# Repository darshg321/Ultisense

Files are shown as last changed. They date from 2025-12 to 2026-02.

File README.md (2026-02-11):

# Ultisense

an esp32-s3 devboard made to sense as many things as possible

has:
- an NFC antenna
- 6DOF IMU
- VOC air sensor
- humidity & temperature sensor
- color & ambient light sensor
- magnetometer

it additionally has:
- microphone
- two speakers
- microSD card


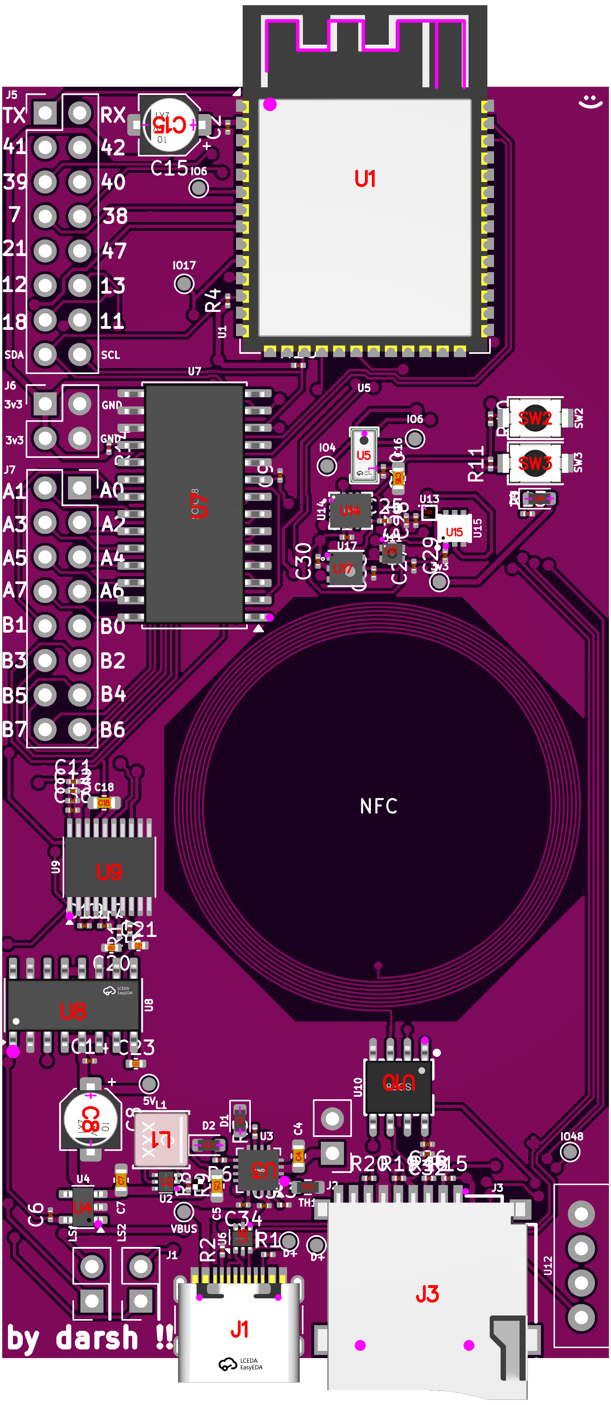
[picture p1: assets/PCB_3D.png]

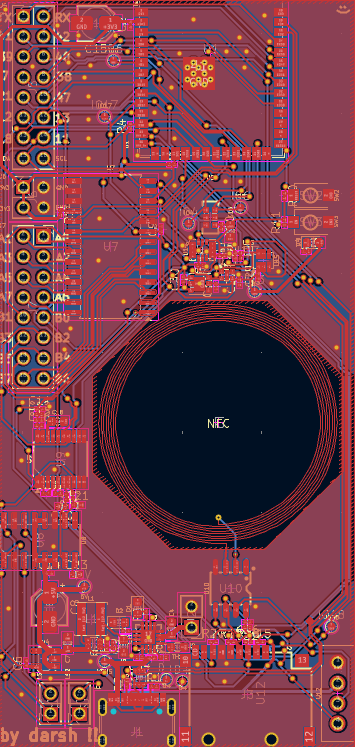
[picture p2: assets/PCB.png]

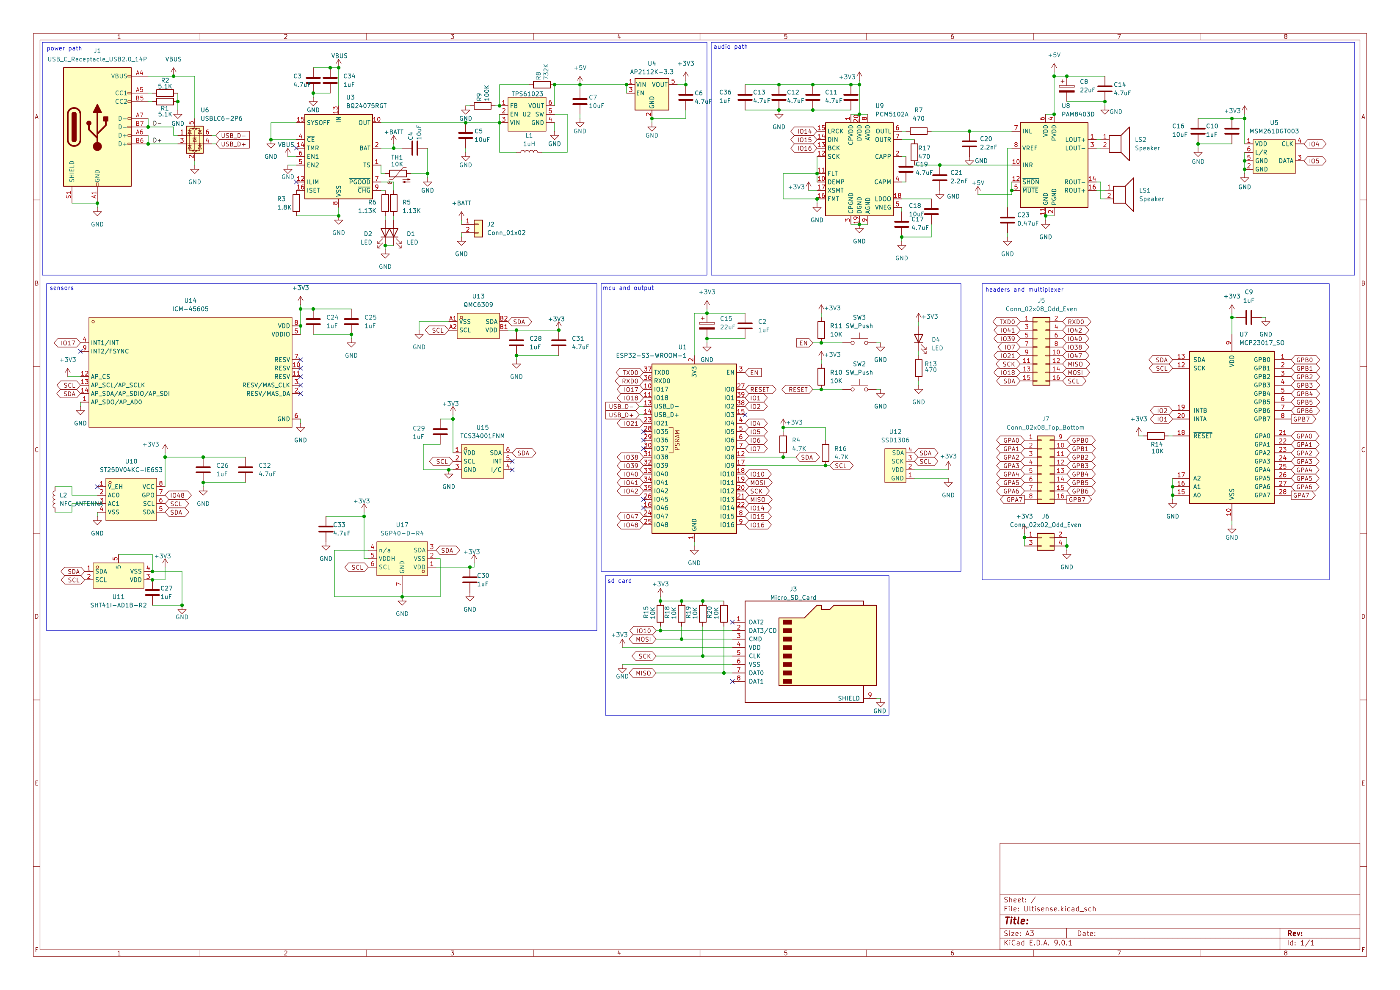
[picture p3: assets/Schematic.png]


## BOM

|Item|Qty |Price (USD) |
|----|---|---|
|PCB |5 |4 |
|PCBA|2 |161.91 |
|Shipping (GSDL)| |12.36 |

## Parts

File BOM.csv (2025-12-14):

Item | Qty | Price (USD)
PCB | 5 | 4
PCBA | 2 | 161.91
Shipping (GSDL) |  | 12.36

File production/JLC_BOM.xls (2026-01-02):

Comment | Designator | Footprint | JLCPCB Part #
SGP40-D-R4 | U17 | DFN-6-EP(2.4x2.4) | C2874215
BQ24075RGT | U3 | QFN-16-EP(3x3) | C15464
USB_C_Receptacle_USB2.0_14P | J1 | SMD | C165948
AP2112K-3.3 | U4 | SOT-23-5 | C23380830
SW_Push | SW2,SW3 | SMD,4x3mm | C720477
TCS34001FNM | U15 | DFN-6(2x2.4) | C2153593
470 | R13,R17,R7 | 0201 | C473464
PCM5102A | U9 | TSSOP-20 | C107671
SHT41I-AD1B-R2 | U11 | DFN-4 | C3664410
4.7K | R16,R4 | 0201 | C138135
LED | D1,D2,D4 | 0603 | C2286
ICM-45605 | U14 | LGA-14 | C38673635
10uF | C16,C18,C4,C5,C7 | 0603 | C1691
2.2nF | C20,C21 | 0402 | C84703
732K | R8 | 0201 | C851791
QMC6309 | U13 | WLCSP-4(0.8x0.8) | C5439871
4.7uF | C11,C12,C13,C14,C17,C19,C3,C31,C32,C33,C6 | 0201 | C335103
1.13K | R5,R6 | 0201 | C166381
ESP32-S3-WROOM-1 | U1 | SMD,25.5x18mm | C2913202
1uH | L1 | SMD,4x4mm | C4555951
5.1K | R1,R2 | 0201 | C163490
USBLC6-2P6 | U6 | SOT-666-6 | C15999
100K | R9 | 0201 | C102685
22uF | C15,C8 | SMD,D4xL5.4mm | C72502
10K | TH1 | 0603 | C13564
Micro_SD_Card | J3 | SMD | C393941
1uF | C10,C2,C24,C25,C26,C27,C28,C29,C30,C34,C36,C9 | 0201 | C76929
MSM261DGT003 | U5 | LGA-6(2x4) | C48227730
TPS61023 | U2 | SOT-563 | C919459
0.47uF | C23 | 0402 | C47339
1.8K | R3 | 0201 | C158752
MCP23017_SO | U7 | SOIC-28-300mil | C629440
PAM8403D | U8 | SOIC-16 | C17337
ST25DV04KC-IE6S3 | U10 | SO-8 | C3304276
10K | R10,R11,R14,R15,R18,R19,R20 | 0201 | C106225

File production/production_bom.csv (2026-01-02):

Designator | Footprint | Quantity | Value | LCSC Part #
C10, C2, C24, C25, C26, C27, C28, C29, C30, C34, C36, C9 | 0201 | 12 | 1uF
C11, C12, C13, C14, C17, C19, C3, C31, C32, C33, C6 | 0201 | 11 | 4.7uF
C15, C8 | CP_Elec_4x5.4 | 2 | 22uF
C16, C18, C4, C5, C7 | 0603 | 5 | 10uF
C20, C21 | 0402 | 2 | 2.2nF
C23 | 0402 | 1 | 0.47uF
D1, D2, D4 | 0603 | 3 | LED
J1 | USB_C_Receptacle_HRO_TYPE-C-31-M-12 | 1 | USB_C_Receptacle_USB2.0_14P
J2 | PinHeader_1x02_P2.54mm_Vertical | 1 | Conn_01x02
J3 | TF-SMD_TF-PUSH | 1 | Micro_SD_Card
J5 | PinHeader_2x08_P2.54mm_Vertical | 1 | Conn_02x08_Odd_Even
J6 | PinHeader_2x02_P2.54mm_Vertical | 1 | Conn_02x02_Odd_Even
J7 | PinSocket_2x08_P2.54mm_Vertical | 1 | Conn_02x08_Top_Bottom
L1 | IND-SMD_L4.0-W4.0-A | 1 | 1uH
LS1, LS2 | PinHeader_2x01_P2.54mm_Vertical | 2 | Speaker
R1, R2 | 0201 | 2 | 5.1K
R10, R11, R14, R15, R18, R19, R20 | 0201 | 7 | 10K
R13, R17, R7 | 0201 | 3 | 470
R16, R4 | 0201 | 2 | 4.7K
R3 | 0201 | 1 | 1.8K
R5, R6 | 0201 | 2 | 1.13K
R8 | 0201 | 1 | 732K
R9 | 0201 | 1 | 100K
SW2, SW3 | SW-SMD_L3.9-W3.0-P4.45 | 2 | SW_Push
TH1 | 0603 | 1 | 10K
U1 | ESP32-S3-WROOM-1 | 1 | ESP32-S3-WROOM-1
U10 | SO-8_L4.9-W3.9-P1.27-LS5.9-BL | 1 | ST25DV04KC-IE6S3 | C3304276
U11 | SENSOR-SMD_4P-L1.5-W1.5-P1.00-TL | 1 | SHT41I-AD1B-R2 | C3664410
U12 | SSD1306 | 1 | SSD1306
U13 | X1-WLB0808-4_L0.8-W0.8-P0.40-TL | 1 | QMC6309 | C5439871
U14 | LGA-14_L3.0-W2.5-P0.50-TL | 1 | ICM-45605 | C38673635
U15 | DFN-6_L2.4-W2.0-P0.65-BL | 1 | TCS34001FNM | C2153593
U17 | DFN-6_L2.4-W2.4-P0.80-TL-EP | 1 | SGP40-D-R4 | C2874215
U2 | SOT-563_L1.6-W1.2-P0.50-LS1.6-BR | 1 | TPS61023
U3 | VQFN-16-1EP_3x3mm_P0.5mm_EP1.6x1.6mm | 1 | BQ24075RGT
U4 | SOT-23-5 | 1 | AP2112K-3.3
U5 | MIC-SMD_6P-L4.0-W2.0_LMD4020T261-OC3 | 1 | MSM261DGT003
U6 | SOT-666 | 1 | USBLC6-2P6
U7 | SOIC-28W_7.5x17.9mm_P1.27mm | 1 | MCP23017_SO
U8 | SOP-16_3.9x9.9mm_P1.27mm | 1 | PAM8403D
U9 | TSSOP-20_4.4x6.5mm_P0.65mm | 1 | PCM5102A

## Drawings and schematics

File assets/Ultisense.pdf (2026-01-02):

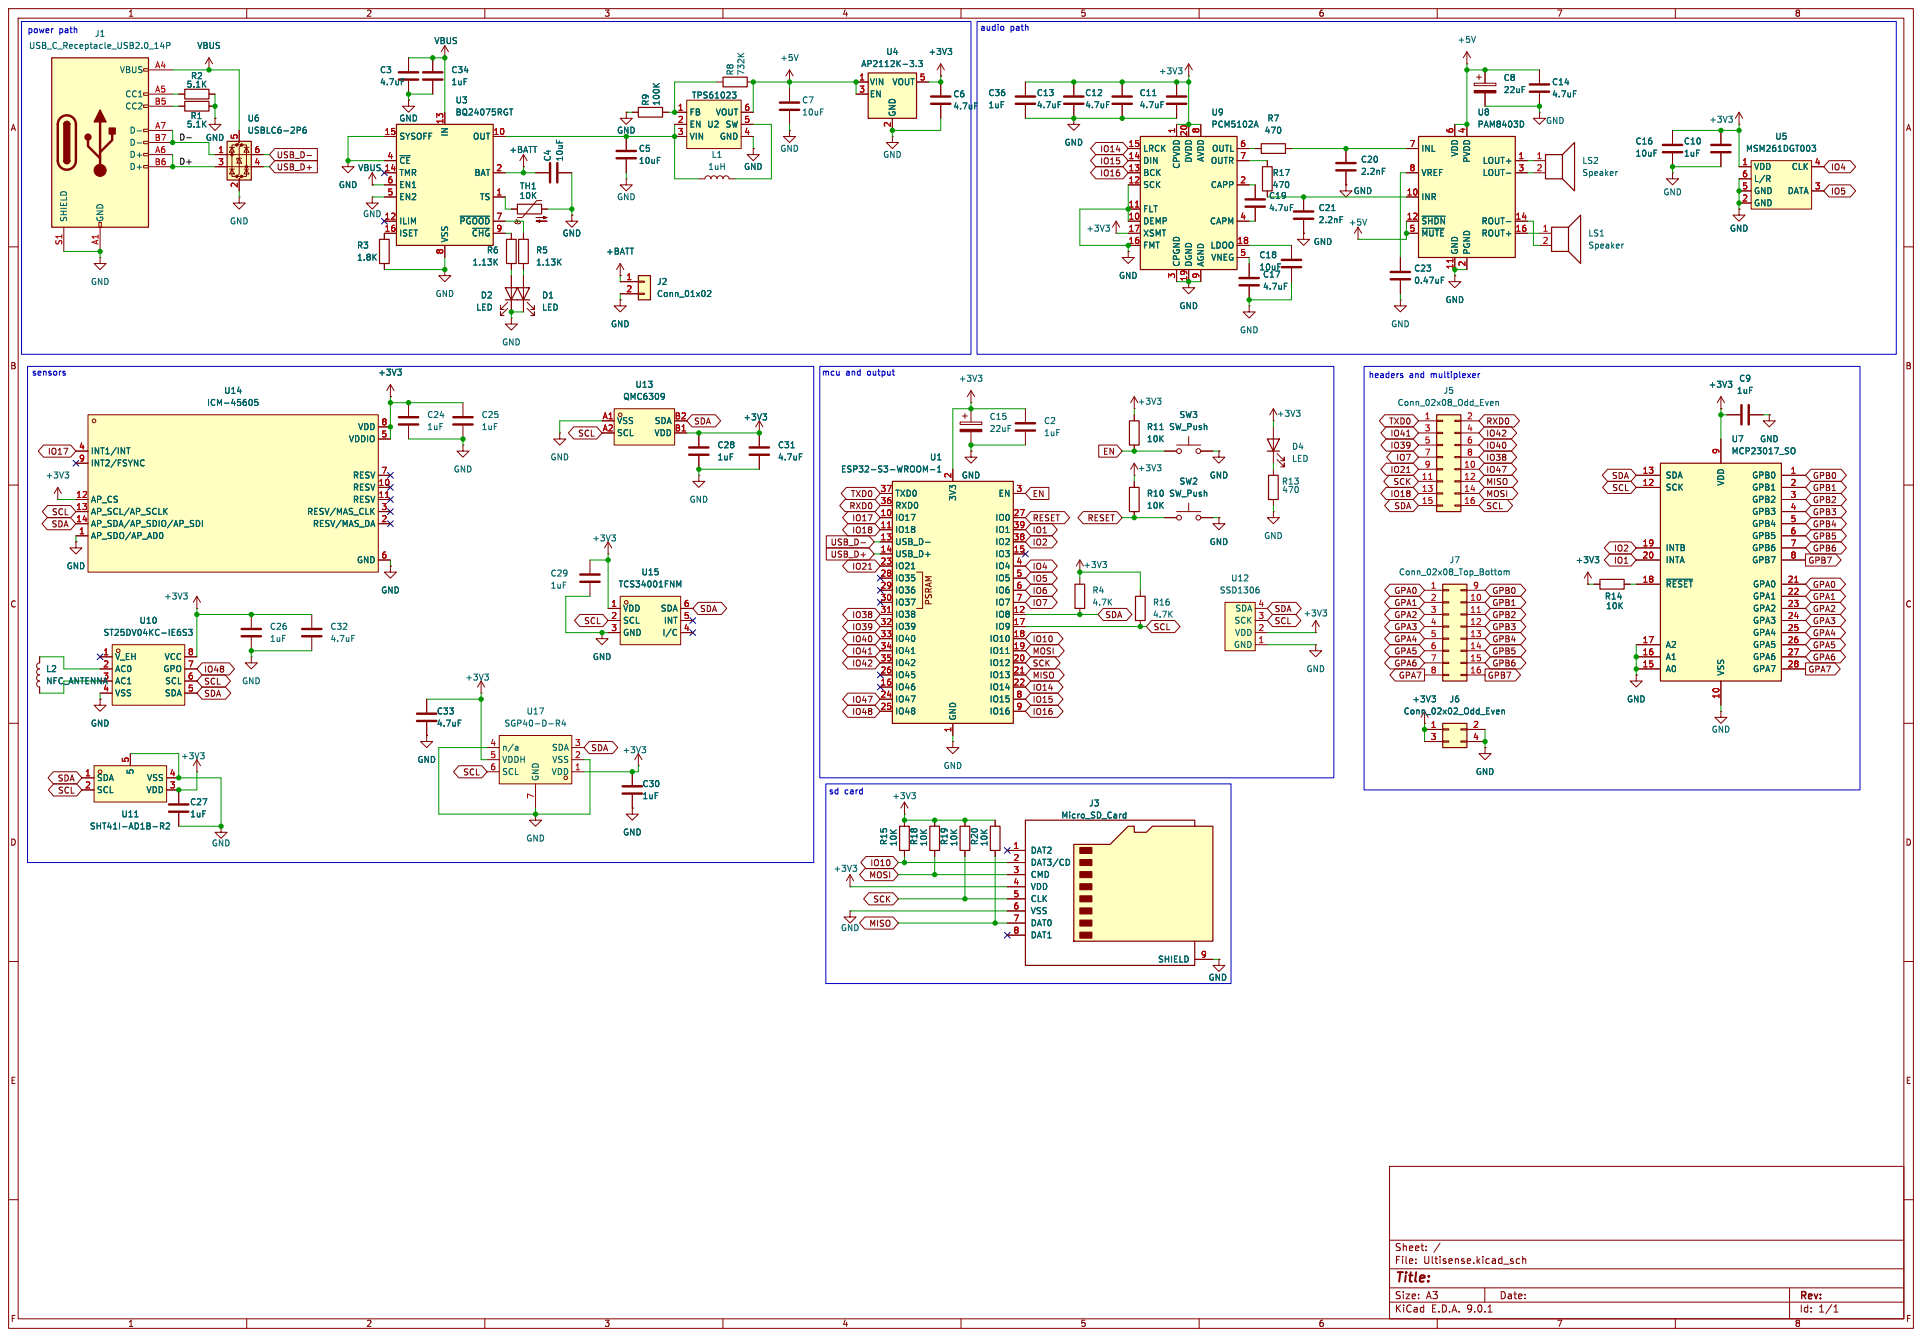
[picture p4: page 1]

8 OUT 10 BAT 2 TS 1 ~{PGOOD}7 ~{CHG}9 C34

8 OUT 10 BAT 2 TS 1 ~{PGOOD}7 ~{CHG}9 U3BQ24075RGT GND

9 OUTL 6 OUTR 7 CAPP 2 CAPM 4

+3V3 VDD 1 VSS 2 SDA 3 GND

EN MISO MOSI SCK

Id: 1/1 Title: File: Ultisense.kicad_sch Sheet: /

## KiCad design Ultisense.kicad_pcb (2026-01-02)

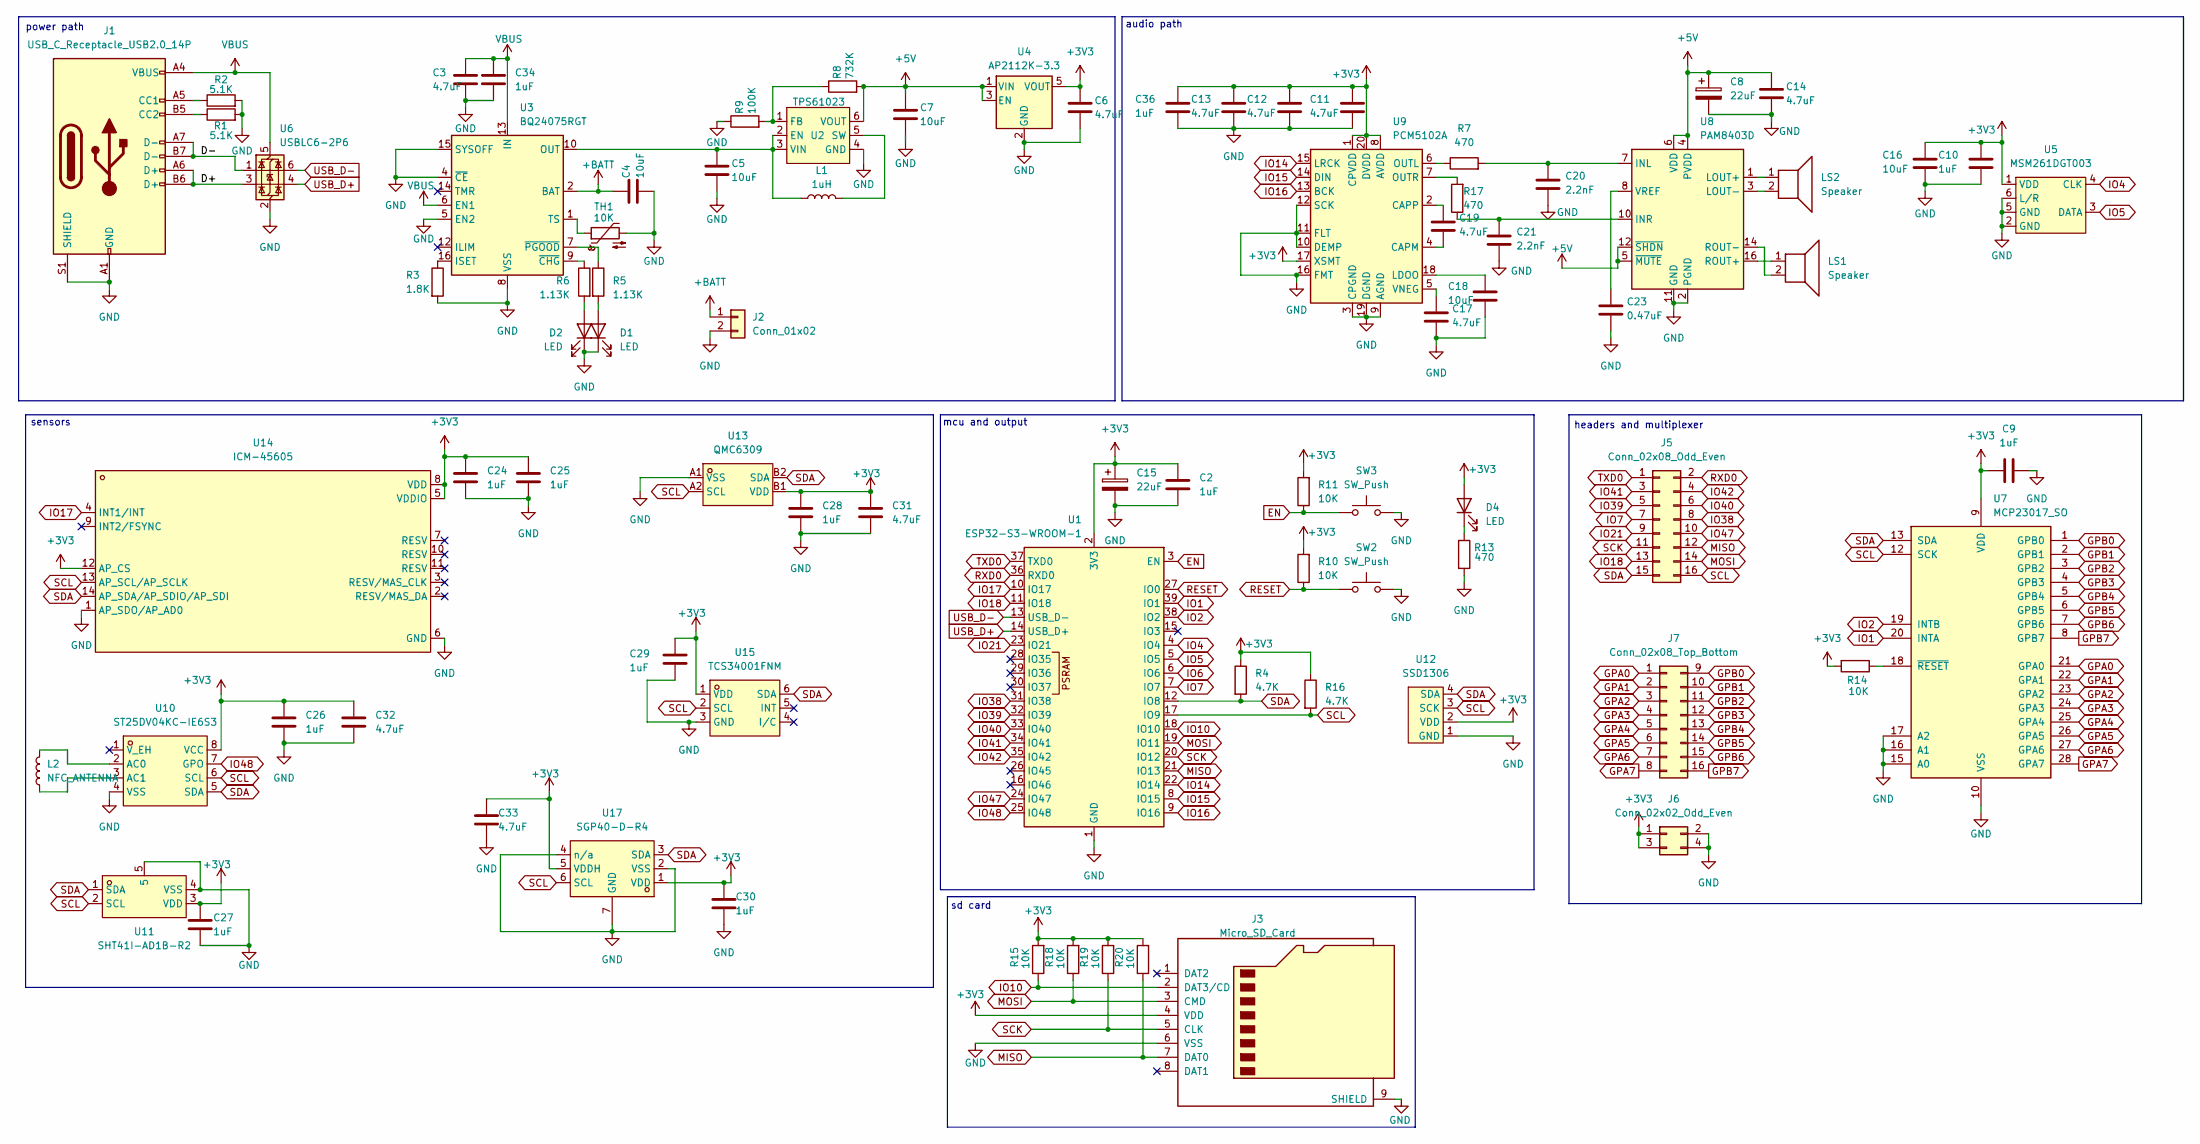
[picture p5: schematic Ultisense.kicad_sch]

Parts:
C2, C9, C10, C24, C25, C26, C27, C28, C29, C30, C34, C36: 1uF; C_0201_0603Metric
C3, C6, C11, C12, C13, C14, C17, C19, C31, C32, C33: 4.7uF; C_0201_0603Metric
C4, C5, C7, C16, C18: 10uF; C_0603_1608Metric
C8, C15: 22uF; CP_Elec_4x5.4
C20, C21: 2.2nF; C_0402_1005Metric
C23: 0.47uF; C_0402_1005Metric
D1, D2, D4: LED; LED_0603_1608Metric
J1: USB_C_Receptacle_USB2.0_14P; USB_C_Receptacle_HRO_TYPE-C-31-M-12
J2: Conn_01x02; PinHeader_1x02_P2.54mm_Vertical
J3: Micro_SD_Card; TF-SMD_TF-PUSH
J5: Conn_02x08_Odd_Even; PinHeader_2x08_P2.54mm_Vertical
J6: Conn_02x02_Odd_Even; PinHeader_2x02_P2.54mm_Vertical
J7: Conn_02x08_Top_Bottom; PinSocket_2x08_P2.54mm_Vertical
L1: 1uH; IND-SMD_L4.0-W4.0-A
L2: NFC_ANTENNA; NFC_Coil
LS1, LS2: Speaker; PinHeader_2x01_P2.54mm_Vertical
R1, R2: 5.1K; R_0201_0603Metric
R3: 1.8K; R_0201_0603Metric
R4, R16: 4.7K; R_0201_0603Metric
R5, R6: 1.13K; R_0201_0603Metric
R7, R13, R17: 470; R_0201_0603Metric
R8: 732K; R_0201_0603Metric
R9: 100K; R_0201_0603Metric
R10, R11, R14, R15, R18, R19, R20: 10K; R_0201_0603Metric
SW2, SW3: SW_Push; SW-SMD_L3.9-W3.0-P4.45
TH1: 10K; R_0603_1608Metric
U1: ESP32-S3-WROOM-1
U2: TPS61023; SOT-563_L1.6-W1.2-P0.50-LS1.6-BR
U3: BQ24075RGT; VQFN-16-1EP_3x3mm_P0.5mm_EP1.6x1.6mm
U4: AP2112K-3.3; SOT-23-5
U5: MSM261DGT003; MIC-SMD_6P-L4.0-W2.0_LMD4020T261-OC3
U6: USBLC6-2P6; SOT-666
U7: MCP23017_SO; SOIC-28W_7.5x17.9mm_P1.27mm
U8: PAM8403D; SOP-16_3.9x9.9mm_P1.27mm
U9: PCM5102A; TSSOP-20_4.4x6.5mm_P0.65mm
U10: ST25DV04KC-IE6S3; SO-8_L4.9-W3.9-P1.27-LS5.9-BL; LCSC Part C3304276
U11: SHT41I-AD1B-R2; SENSOR-SMD_4P-L1.5-W1.5-P1.00-TL; LCSC Part C3664410
U12: SSD1306
U13: QMC6309; X1-WLB0808-4_L0.8-W0.8-P0.40-TL; LCSC Part C5439871
U14: ICM-45605; LGA-14_L3.0-W2.5-P0.50-TL; LCSC Part C38673635
U15: TCS34001FNM; DFN-6_L2.4-W2.0-P0.65-BL; LCSC Part C2153593
U17: SGP40-D-R4; DFN-6_L2.4-W2.4-P0.80-TL-EP; LCSC Part C2874215

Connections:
+3V3: C2.2, C6.1, C9.1, C10.1, C11.1, C12.1, C13.1, C15.1, C16.1, C24.1, C25.1, C26.2, C27.2, C28.2, C29.2, C30.2, C31.2, C32.2, C33.2, C36.1, D4.2 (A), J3.4 (VDD), J6.1, J6.3, R4.1, R10.2, R11.2, R14.2, R15.2, R16.1, R18.2, R19.2, R20.2, U1.2 (3V3), U4.5 (VOUT), U5.1 (VDD), U7.9 (VDD), U9.1 (CPVDD), U9.8 (AVDD), U9.17 (XSMT), U9.20 (DVDD), U10.8 (VCC), U11.3 (VDD), U12.2 (VDD), U13.B1 (VDD), U14.5 (VDDIO), U14.8 (VDD), U14.12 (AP_CS), U15.1 (VDD), U17.1 (VDD), U17.5 (VDDH); also elsewhere on the board
+5V: C7.1, C8.1, C14.1, R8.2, U2.6 (VOUT), U4.1 (VIN), U4.3 (EN), U8.4 (PVDD), U8.5 (~MUTE), U8.6 (VDD), U8.12 (~SHDN), U8.13 (PVDD); also elsewhere on the board
+BATT: C4.1, J2.1, U3.2 (BAT), U3.3 (BAT)
/D+: J1.A6 (D+), J1.B6 (D+), U6.3 (I/O2); also elsewhere on the board
/D-: J1.A7 (D-), J1.B7 (D-), U6.1 (I/O1); also elsewhere on the board
EN: R11.1, SW3.1, U1.3 (EN)
GND: C2.1, C3.2, C4.2, C5.2, C6.2, C7.2, C8.2, C9.2, C10.2, C11.2, C12.2, C13.2, C14.2, C15.2, C16.2, C17.2, C18.2, C20.2, C21.2, C23.2, C24.2, C25.2, C26.1, C27.1, C28.1, C29.1, C30.1, C31.1, C32.1, C33.1, C34.2, C36.2, D1.1 (K), D2.1 (K), J1.A1 (GND), J1.A12 (GND), J1.B1 (GND), J1.B12 (GND), J1.S1 (SHIELD), J2.2, J3.6 (VSS), J3.9 (SHIELD), J6.2, J6.4, R1.2, R2.2, R3.2, R9.1, R13.2, SW2.2, SW3.2, TH1.2, U1.1 (GND), U1.40 (GND), U1.41 (GND), U2.4 (GND), U3.4 (~CE), U3.5 (EN2), U3.8 (VSS), U3.15 (SYSOFF), U3.17 (VSS), U4.2 (GND), U5.2 (GND), U5.5 (GND), U5.6 (L/R), U6.2 (GND), U7.10 (VSS), U7.15 (A0), U7.16 (A1), U7.17 (A2), U8.2 (PGND), U8.11 (GND), U8.15 (PGND), U9.3 (CPGND), U9.9 (AGND), U9.10 (DEMP), U9.11 (FLT), U9.12 (SCK), U9.16 (FMT), U9.19 (DGND), U10.4 (VSS), U11.4 (VSS), U11.5, U12.1 (GND), U13.A1 (VSS), U14.1 (AP_SDO/AP_AD0), U14.6 (GND), U15.3 (GND), U17.2 (VSS), U17.4 (n/a), U17.7 (GND)
GPA0: J7.1, U7.21 (GPA0)
GPA1: J7.2, U7.22 (GPA1)
GPA2: J7.3, U7.23 (GPA2)
GPA3: J7.4, U7.24 (GPA3)
GPA4: J7.5, U7.25 (GPA4)
GPA5: J7.6, U7.26 (GPA5)
GPA6: J7.7, U7.27 (GPA6)
GPA7: J7.8, U7.28 (GPA7)
GPB0: J7.9, U7.1 (GPB0)
GPB1: J7.10, U7.2 (GPB1)
GPB2: J7.11, U7.3 (GPB2)
GPB3: J7.12, U7.4 (GPB3)
GPB4: J7.13, U7.5 (GPB4)
GPB5: J7.14, U7.6 (GPB5)
GPB6: J7.15, U7.7 (GPB6)
GPB7: J7.16, U7.8 (GPB7)
IO1: U1.39 (IO1), U7.20 (INTA)
IO2: U1.38 (IO2), U7.19 (INTB)
IO4: U1.4 (IO4), U5.4 (CLK); also elsewhere on the board
IO5: U1.5 (IO5), U5.3 (DATA); also elsewhere on the board
IO6: U1.6 (IO6); also elsewhere on the board
IO7: J5.7, U1.7 (IO7)
IO10: J3.2 (DAT3/CD), R15.1, U1.18 (IO10)
IO14: U1.22 (IO14), U9.15 (LRCK)
IO15: U1.8 (IO15), U9.14 (DIN)
IO16: U1.9 (IO16), U9.13 (BCK)
IO17: U1.10 (IO17), U14.4 (INT1/INT); also elsewhere on the board
IO18: J5.13, U1.11 (IO18)
IO21: J5.9, U1.23 (IO21)
IO38: J5.8, U1.31 (IO38)
IO39: J5.5, U1.32 (IO39)
IO40: J5.6, U1.33 (IO40)
IO41: J5.3, U1.34 (IO41)
IO42: J5.4, U1.35 (IO42)
IO47: J5.10, U1.24 (IO47)
IO48: U1.25 (IO48), U10.7 (GPO); also elsewhere on the board
MISO: J3.7 (DAT0), J5.12, R20.1, U1.21 (IO13)
MOSI: J3.3 (CMD), J5.14, R18.1, U1.19 (IO11)
unnamed: D1.2 (A), R5.2
unnamed: D2.2 (A), R6.2
unnamed: D4.1 (K), R13.1
unnamed: J1.A5 (CC1), R2.1
unnamed: J1.B5 (CC2), R1.1
unnamed: C5.1, L1.1, U2.2 (EN), U2.3 (VIN), U3.10 (OUT), U3.11 (OUT)
unnamed: R8.1, R9.2, U2.1 (FB)
unnamed: L1.2, U2.5 (SW)
unnamed: R3.1, U3.16 (ISET)
unnamed: TH1.1, U3.1 (TS)
unnamed: R6.1, U3.9 (~CHG)
unnamed: R5.1, U3.7 (~PGOOD)
unnamed: R14.1, U7.18 (~RESET)
unnamed: C20.1, R7.2, U8.7 (INL)
unnamed: C21.1, R17.1, U8.10 (INR)
unnamed: LS2.1, U8.1 (LOUT+)
unnamed: LS2.2, U8.3 (LOUT-)
unnamed: LS1.1, U8.16 (ROUT+)
unnamed: LS1.2, U8.14 (ROUT-)
unnamed: C23.1, U8.8 (VREF)
unnamed: C19.2, U9.4 (CAPM)
unnamed: C19.1, U9.2 (CAPP)
unnamed: C18.1, U9.18 (LDOO)
unnamed: R7.1, U9.6 (OUTL)
unnamed: R17.2, U9.7 (OUTR)
unnamed: C17.1, U9.5 (VNEG)
unnamed: L2.2, U10.2 (AC0)
unnamed: L2.1, U10.3 (AC1)
RESET: R10.1, SW2.1, U1.27 (IO0)
RXD0: J5.2, U1.36 (RXD0)
SCK: J3.5 (CLK), J5.11, R19.1, U1.20 (IO12)
SCL: J5.16, R16.2, U1.17 (IO9), U7.12 (SCK), U10.6 (SCL), U11.2 (SCL), U12.3 (SCK), U13.A2 (SCL), U14.13 (AP_SCL/AP_SCLK), U15.2 (SCL), U17.6 (SCL)
SDA: J5.15, R4.2, U1.12 (IO8), U7.13 (SDA), U10.5 (SDA), U11.1 (SDA), U12.4 (SDA), U13.B2 (SDA), U14.14 (AP_SDA/AP_SDIO/AP_SDI), U15.6 (SDA), U17.3 (SDA)
TXD0: J5.1, U1.37 (TXD0)
USB_D+: U1.14 (USB_D+), U6.4 (I/O2)
USB_D-: U1.13 (USB_D-), U6.6 (I/O1)
VBUS: C3.1, C34.1, J1.A4 (VBUS), J1.A9 (VBUS), J1.B4 (VBUS), J1.B9 (VBUS), U3.6 (EN1), U3.13 (IN), U6.5 (VBUS); also elsewhere on the board

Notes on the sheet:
headers and multiplexer
sensors
audio path
power path
sd card
mcu and output

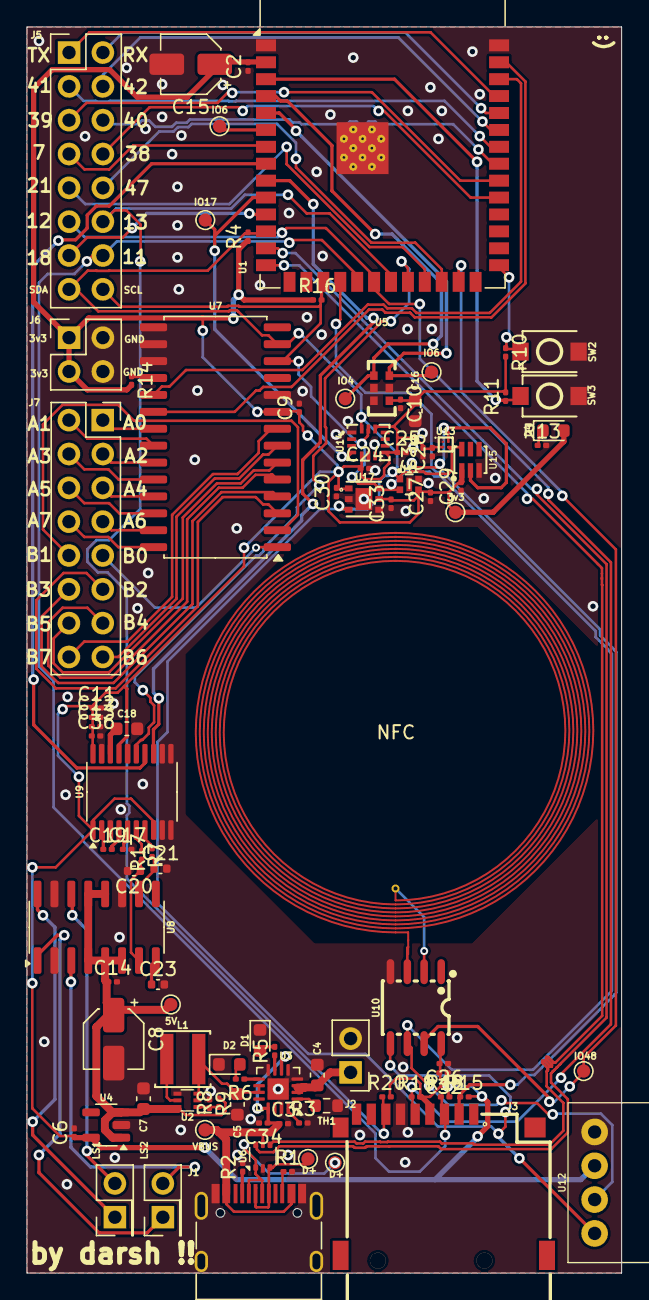
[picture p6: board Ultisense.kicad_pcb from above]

Board: 2 copper layers, 44.7 x 93.6 mm, 94 parts (0 on the bottom side), 82 nets.

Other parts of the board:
3v3, 5V: TestPoint_Pad_D1.0mm
D+: TestPoint_Pad_D1.0mm
D+#2: TestPoint_Pad_D1.0mm
IO4, IO6, IO6#2, IO17, IO48: TestPoint_Pad_D1.0mm
VBUS: TestPoint_Pad_D1.0mm

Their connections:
+3V3: 3v3.1; also elsewhere on the board
+5V: 5V.1; also elsewhere on the board
/D+: D+.1; also elsewhere on the board
/D-: D+#2.1; also elsewhere on the board
IO4: IO4.1; also elsewhere on the board
IO5: IO6.1; also elsewhere on the board
IO6: IO6#2.1; also elsewhere on the board
IO17: IO17.1; also elsewhere on the board
IO48: IO48.1; also elsewhere on the board
VBUS: VBUS.1; also elsewhere on the board

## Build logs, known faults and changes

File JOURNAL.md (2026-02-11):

<!--
  This journal is auto generated by Hack Club Blueprint.
-->

# 11/8/2025 6 PM - planning...  

_Time spent: 1.5h_  

features i want it to have:
-esp32-s3 chip with cool working wifi/bluetooth
large

-usbc 100w power, charging to lipo battery (not actually 100w) while running off of usb power or battery, esd protection
-multiplexer
-imu
-oled screen
-temperature sensing
-touch sensor
-microphone + speaker
-espcam module
-bunch of leds
-5v output
-ir blaster
-buttons
-ultrasonic sensor
-sd card reader
-headers for 3v3, 5v, 9v, 12v  

# 11/8/2025 11 PM - bom  

_Time spent: 3.0h_  

-esp32-s3-wroom MCU
-CP2102 UART chip
-GY-87 IMU
-TTP223 touch sensor
-LM75A temperature sensor
-MSM261DGT003 microphone
-HC-SR04 ultrasonic sensor
-OV5640 camera
-TS-1088-AR02016 buttons
-SSD1306 OLED screen

audio: 
-PAM8403 amplifier
-8ohm 1W speaker

led: KT-0603R
sd: TF PUSH
nfc: PN532 module
multiplexer: CD4051BM96

power:
-TYPE-C-31-M-12
-BQ24075 charger
-2 pin jst housing (for batt)
-AP2112K-3.3 3v3 LDO
-TPS61023DRLT boost converter

ultisense

# 11/9/2025 10 PM - added power path  

_Time spent: 3.0h_  

added all of my power path stuff
flow:
usb 2.0
data goes through esd protection, to mcu data
vbus goes to BQ24075 which charges at 500mA and has two leds for status, outputs usb if connected otherwise battery
output goes to TPS61023, 5v boost to 5v rail
also goes to an ldo which outputs to 3v3 rail



# 11/9/2025 11 PM - mcu + multiplexer + sd card  

_Time spent: 1.5h_  

added mcu buttons and multiplexer (using mcp23017 bc other one is analog), and also wired the sd card. thats it basically; using i2c for multiplexer and spi for sd card



# 11/10/2025 - audio path  

_Time spent: 3.0h_  

added the audio path !!
it goes from the pcm DAC, to the pamb403 amplifier, to the 2 l, r speakers which will be 8ohm
also added a microphone that im planning to use for basic commands
misc fixes: added an ntc thermistor, pull ups to the sda/scl



# 11/11/2025 - finished schematic  

_Time spent: 3.0h_  

finished schematic; adding footprints now
found a tool called easyeda2kicad that lets me download the jlc parts footprints which makes it a lot more convenient and wouldve saved me time in creating footprints



# 11/23/2025 - finished schematic fully and starting pcb  

_Time spent: 4.0h_  

went back and forth on multiple things so this took way longer than it really needed to, since i also researched and designed like 4 things i ended up just deleting. initially i was going to just use modules for both capacitive touch and nfc because they're kind of a hassle but after seeing the size and how conflicting they would look on the pcb anyways, i decided to just have both. theyll probably both be less reliable (especially the touch sensor since im using the esp32s3 gpio which isnt even certified but oh well. new schematic:



new pcb:


i have to keep in mind all the keepout for the different components, and the size of the power traces, and routing everything properly.

# 11/24/2025 - added a few more sensors  

_Time spent: 2.0h_  

added temperature, humidity, color/lux sensor, magnetometer. not much more to say but im officially for real done with the schematic. i also figured out the nfc antenna, hopefully my numbers are correct. 





# 11/25/2025 10 AM - routing  

_Time spent: 1.5h_  

design considerations i must follow:
- usb c at one edge
- esp32s3 antenna at other edge
- sd card on side edge
- headers on other side edge
- very minimal traces through nfc antenna
- battery connection at side edge
- two speakers; one on each edge
- microphone in middle
- imu in middle
- touch pad at edge
partial routing:


# 11/25/2025 9 PM - pcb layout done and grouped  

_Time spent: 0.5h_  

layout done and everything is now grouped and the within groups are routed. i need to route the full board now, might be terrible because i tried to minimize spacing; but hopefully it wont be like impossible. might get rid of the oled screen for just being unnecessary.





# 11/28/2025 3 PM - routing done!!  

_Time spent: 2.5h_  

finally finished routing, also added the gnd pour and stitching vias. it actually wasnt that bad, the process i did this time with grouping sections together and making a layout, and additionally giving myself some space definitely made it miles more pleasant to do. definitely couldve made this board smaller but its not like that matters for me with this board so oh well.



# 11/28/2025 6:02 PM - done !!  

_Time spent: 1.0h_  

added silkscreen, fixed the jlcpcb BOM and placements; the cost ended up being literally $199.99 which is kinda cooked, pcb assembly is so expensive especially since all the sensors are extended, and i cant get the cheap shipping because the pcba is more than $99.





# 11/28/2025 6:46 PM - banner  

_Time spent: 0.1h_  

--------------------------------------------------------------------banner---------------------------------------------------------------------------:

banner

# 12/1/2025 - fixed nfc  

_Time spent: 2.0h_  

completely forgot about the gnd place oops. also apparently no traces are allowed to cross the coil at all, contrary to what i read of some straight ones being allowed. so fixed the nfc antenna issues, removed capacitive touch because there's no space to put it anywhere, and also cleaned some things. moved the oled to a different spot, and now have a lot of space on my board but unfortunately not enough to actually make the board smaller. also added some test points in case i need them



# 2/10/2026 - made it work!!!  

_Time spent: 3.0h_  

i initially tried this the second it shipped but it didnt work for some reason; i thought i messed up in the i2c wiring because all three sensors i tried out from the beginning refused to give me any data. i then asked for help in 1bitsquared which is a goated community, who pointed me into using a logic analyzer which i conveniently had stashed away from a random aliexpress order many months ago. soldered the headers on and connected it to view the data, and instead found that miraculously it had started working, and after troubleshooting a lot with the board type in arduino because it would refuse to compile otherwise, i got it actually working from the code (also made a custom board for the board manager of the ide). then adapted the gpt code into the library code, and got a voc index reading by using the sensiron algorithm (note that it takes a while to warm up the sensor before getting real readings), and now it gives accurate data!! hovers around 90-120 VOC Index in my room, and when i breathe on it it spikes up to like 200 which is exactly what its supposed to be doing which is goated !! will test the other sensors later, and figure out how logic analyzer actually works





BUILD

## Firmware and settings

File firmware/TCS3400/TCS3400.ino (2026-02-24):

#include <Wire.h>

#define SDA_PIN 8
#define SCL_PIN 9

#define TCS3400_ADDR 0x39

// Registers
#define ENABLE_REG   0x80
#define ATIME_REG    0x81
#define CONTROL_REG  0x8F
#define STATUS_REG   0x93

#define CDATAL       0x94
#define RDATAL       0x96
#define GDATAL       0x98
#define BDATAL       0x9A
#define IR_REG       0xC0

// ENABLE bits
#define PON  0x01
#define AEN  0x02

void writeRegister(uint8_t reg, uint8_t value) {
  Wire.beginTransmission(TCS3400_ADDR);
  Wire.write(reg);
  Wire.write(value);
  Wire.endTransmission();
}

uint8_t readRegister8(uint8_t reg) {
  Wire.beginTransmission(TCS3400_ADDR);
  Wire.write(reg);
  Wire.endTransmission();
  Wire.requestFrom(TCS3400_ADDR, (uint8_t)1);
  return Wire.available() ? Wire.read() : 0;
}

uint16_t readRegister16(uint8_t reg) {
  Wire.beginTransmission(TCS3400_ADDR);
  Wire.write(reg);
  Wire.endTransmission();
  Wire.requestFrom(TCS3400_ADDR, (uint8_t)2);
  if (Wire.available() < 2) return 0;
  uint8_t low = Wire.read();
  uint8_t high = Wire.read();
  return (high << 8) | low;
}

void initTCS3400() {
  writeRegister(ENABLE_REG, PON);
  delay(10);

  writeRegister(ATIME_REG, 0xF6);      // ~27.8ms integration
  writeRegister(CONTROL_REG, 0x02);    // 16x gain

  writeRegister(ENABLE_REG, PON | AEN);
  delay(50);
}

void readAllChannels(
  uint16_t &clear,
  uint16_t &red,
  uint16_t &green,
  uint16_t &blue,
  uint16_t &ir
) {
  clear = readRegister16(CDATAL);
  red   = readRegister16(RDATAL);
  green = readRegister16(GDATAL);
  blue  = readRegister16(BDATAL);

  // Enable IR mapping to clear channel
  writeRegister(IR_REG, 0x80);
  delay(5);
  ir = readRegister16(CDATAL);
  writeRegister(IR_REG, 0x00);
}

void setup() {
  Serial.begin(115200);
  delay(1000);
  Serial.println("Serial Started");

  Wire.begin(SDA_PIN, SCL_PIN);
  Wire.setClock(100000);

  initTCS3400();
  Serial.println("TCS34001FNM Color Sensor Started");
}

void loop() {
  uint16_t clear, red, green, blue, ir;
  readAllChannels(clear, red, green, blue, ir);

  if (clear == 0) {
    Serial.println("Read error or no light");
    delay(1000);
    return;
  }

  // Normalize RGB to 0–255 scale
  float rNorm = (float)red   / clear;
  float gNorm = (float)green / clear;
  float bNorm = (float)blue  / clear;

  uint8_t r8 = constrain(rNorm * 255, 0, 255);
  uint8_t g8 = constrain(gNorm * 255, 0, 255);
  uint8_t b8 = constrain(bNorm * 255, 0, 255);

  uint32_t visible = (clear > ir) ? (clear - ir) : 0;

  float lux = (0.136 * red) +
              (1.000 * green) +
              (-0.444 * blue);

  // Determine dominant color
  String dominant;
  if (r8 > g8 && r8 > b8) dominant = "Red";
  else if (g8 > r8 && g8 > b8) dominant = "Green";
  else if (b8 > r8 && b8 > g8) dominant = "Blue";
  else dominant = "Neutral / White";

  Serial.println("------ RAW DATA ------");
  Serial.print("Clear: "); Serial.println(clear);
  Serial.print("Red:   "); Serial.println(red);
  Serial.print("Green: "); Serial.println(green);
  Serial.print("Blue:  "); Serial.println(blue);
  Serial.print("IR:    "); Serial.println(ir);

  Serial.println("------ HUMAN READABLE ------");
  Serial.print("RGB (0-255): ");
  Serial.print(r8); Serial.print(", ");
  Serial.print(g8); Serial.print(", ");
  Serial.println(b8);

  Serial.print("Visible Counts: ");
  Serial.println(visible);

  Serial.print("Estimated Lux: ");
  Serial.println(lux);

  Serial.print("Dominant Color: ");
  Serial.println(dominant);

  delay(1000);
}

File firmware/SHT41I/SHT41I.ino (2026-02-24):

#include <Wire.h>

#define SDA_PIN 8
#define SCL_PIN 9
#define SHT41_ADDR 0x44

// SHT4x commands
#define CMD_MEAS_HIGHREP 0xFD  // high repeatability (highest precision)
#define CMD_MEAS_MEDREP  0xF6  // medium repeatability
#define CMD_MEAS_LOWREP  0xE0  // low repeatability

// CRC8 (polynomial 0x31), same parameters as Sensirion datasheet
uint8_t sht_crc(uint8_t *data, uint8_t len) {
  uint8_t crc = 0xFF;
  for (uint8_t i = 0; i < len; i++) {
    crc ^= data[i];
    for (uint8_t b = 0; b < 8; b++) {
      if (crc & 0x80)
        crc = (crc << 1) ^ 0x31;
      else
        crc <<= 1;
    }
  }
  return crc;
}

// Send a single-byte command to the sensor
bool sht_write_command(uint8_t cmd) {
  Wire.beginTransmission(SHT41_ADDR);
  Wire.write(cmd);
  if (Wire.endTransmission() != 0) return false;
  return true;
}

// Read one measurement: returns true if read+CRC OK and fills t_ticks/rh_ticks
bool measureRawSHT41(uint16_t &t_ticks, uint16_t &rh_ticks, uint8_t repeatability = CMD_MEAS_HIGHREP) {
  // send measurement command
  if (!sht_write_command(repeatability)) return false;

  // wait for measurement to complete
  // datasheet suggests ~7-9 ms for high, ~3.7-4.5 ms for med, ~1.3-1.6 ms for low
  // use safe delay of 10 ms for high, 5 ms for med, 2 ms for low
  if (repeatability == CMD_MEAS_HIGHREP) delay(10);
  else if (repeatability == CMD_MEAS_MEDREP) delay(6);
  else delay(3);

  // request 6 bytes: T_MSB, T_LSB, CRC, RH_MSB, RH_LSB, CRC
  Wire.requestFrom((uint8_t)SHT41_ADDR, (uint8_t)6);
  if (Wire.available() != 6) return false;

  uint8_t tb0 = Wire.read();
  uint8_t tb1 = Wire.read();
  uint8_t crc_t = Wire.read();
  uint8_t rb0 = Wire.read();
  uint8_t rb1 = Wire.read();
  uint8_t crc_r = Wire.read();

  uint8_t tmp_t[2] = { tb0, tb1 };
  uint8_t tmp_r[2] = { rb0, rb1 };

  // validate CRCs
  if (sht_crc(tmp_t, 2) != crc_t) return false;
  if (sht_crc(tmp_r, 2) != crc_r) return false;

  t_ticks = ((uint16_t)tb0 << 8) | tb1;
  rh_ticks = ((uint16_t)rb0 << 8) | rb1;
  return true;
}

// Read serial number (command 0x89) - returns true if OK and fills serial (32-bit)
bool readSerial(uint32_t &serial) {
  const uint8_t CMD_READ_SERIAL = 0x89;
  if (!sht_write_command(CMD_READ_SERIAL)) return false;
  delay(1); // tiny wait

  Wire.requestFrom((uint8_t)SHT41_ADDR, (uint8_t)6);
  if (Wire.available() != 6) return false;

  uint8_t s0 = Wire.read();
  uint8_t s1 = Wire.read();
  uint8_t crc0 = Wire.read();
  uint8_t s2 = Wire.read();
  uint8_t s3 = Wire.read();
  uint8_t crc1 = Wire.read();

  uint8_t part0[2] = { s0, s1 };
  uint8_t part1[2] = { s2, s3 };

  if (sht_crc(part0, 2) != crc0) return false;
  if (sht_crc(part1, 2) != crc1) return false;

  // Combine words into 32-bit serial (word0 MSB..LSB then word1 MSB..LSB)
  serial = ((uint32_t)s0 << 24) | ((uint32_t)s1 << 16) | ((uint32_t)s2 << 8) | (uint32_t)s3;
  return true;
}

void setup() {
  Serial.begin(115200);
  delay(1000);
  Wire.begin(SDA_PIN, SCL_PIN);
  Wire.setClock(100000);
  Serial.println("SHT41I measurement example started");
}

void loop() {
  uint16_t t_ticks = 0, rh_ticks = 0;
  if (!measureRawSHT41(t_ticks, rh_ticks, CMD_MEAS_HIGHREP)) {
    Serial.println("SHT41 read error (measurement failed or CRC mismatch)");
    delay(1000);
    return;
  }

  // print raw ticks
  Serial.print("T ticks: 0x");
  Serial.print(t_ticks, HEX);
  Serial.print(" (");
  Serial.print(t_ticks);
  Serial.println(")");
  Serial.print("RH ticks: 0x");
  Serial.print(rh_ticks, HEX);
  Serial.print(" (");
  Serial.print(rh_ticks);
  Serial.println(")");

  // convert to physical values using datasheet formulas
  // Use 65535.0 (2^16 - 1) as denominator to match datasheet conversion
  float t_degC = -45.0f + 175.0f * ((float)t_ticks / 65535.0f);
  float t_degF = -49.0f + 315.0f * ((float)t_ticks / 65535.0f); // datasheet formula for °F
  float rh_pct_uncropped = -6.0f + 125.0f * ((float)rh_ticks / 65535.0f);
  float rh_pct = rh_pct_uncropped;
  if (rh_pct > 100.0f) rh_pct = 100.0f;
  if (rh_pct < 0.0f) rh_pct = 0.0f;
  float aw = rh_pct_uncropped / 100.0f; // water activity (aw) as per datasheet (1/100 factor)

  // print converted values
  Serial.print("Temperature: ");
  Serial.print(t_degC, 3);
  Serial.print(" °C | ");
  Serial.print(t_degF, 3);
  Serial.println(" °F");

  Serial.print("Relative Humidity (uncropped): ");
  Serial.print(rh_pct_uncropped, 3);
  Serial.println(" %RH");

  Serial.print("Relative Humidity (cropped 0..100): ");
  Serial.print(rh_pct, 3);
  Serial.println(" %RH");

  Serial.print("Water activity (aw): ");
  Serial.println(aw, 6);

  // optional: print serial number once
  static bool printedSerial = false;
  if (!printedSerial) {
    uint32_t serial = 0;
    if (readSerial(serial)) {
      Serial.print("SHT4x Serial: 0x");
      Serial.println(serial, HEX);
    } else {
      Serial.println("Failed to read serial number or CRC mismatch");
    }
    printedSerial = true;
  }

  Serial.println("----------------------------------------");
  delay(1000); // 1 Hz loop
}

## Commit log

2025-11-10 mcu + power path + multiplexer + sd card
    [Ultisense.kicad_pcb, Ultisense.kicad_sch]
2025-11-23 finished schematic, starting pcb
    [Ultisense.kicad_pcb, Ultisense.kicad_sch]
2025-11-25 actually fr done schematic, figured out nfc antenna
    [Ultisense.kicad_pcb, Ultisense.kicad_sch]
2025-11-26 layout done
    [Ultisense.kicad_pcb, Ultisense.kicad_sch]
2025-11-28 routing almost done; backup:
    [Ultisense.kicad_pcb, Ultisense.kicad_sch]
2025-11-28 routing done !!
    [Ultisense.kicad_pcb]
2025-11-29 headers silkscreen
    [Ultisense.kicad_pcb]
2025-11-30 added test points and changed silkscreen
    [Ultisense.kicad_pcb, production_designators.csv]
2025-12-02 fixed nfc
    [Ultisense.kicad_pcb, Ultisense.kicad_sch, production_designators.csv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]
2025-12-07 replaced out of stock light sensor
    [JLC_BOM.xls, Ultisense.kicad_pcb, Ultisense.kicad_sch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]
2025-12-10 testing firmware
    [JLC_BOM.csv]
2025-12-11 moved csv
    [BOM.csv]
2025-12-14 moved bom yet again
    [BOM.csv, JLC_BOM.csv]
2026-01-02 replaced 01005 with 0201, fixed a few other things, reordering
    [JLC_BOM.csv, JLC_BOM.xls, Ultisense.kicad_pcb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]
